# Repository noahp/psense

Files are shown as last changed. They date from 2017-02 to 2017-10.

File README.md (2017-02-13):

# psense
USB interfaced, 2-channel current + voltage meter.

# Schematic
[Schematic PDF here](psense.pdf)

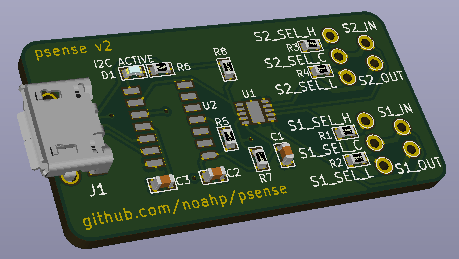
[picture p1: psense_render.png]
Render


# Parts
## USB
* USB to I2C interface
* bus powered, no external crystal needed

http://www.mouser.com/ProductDetail/Microchip-Technology/MCP2221A-I-SL

## Meter
* 2 channel current + bus voltage (0-40V)
* I2C interface
* adjustable range +/-10mV, 20mV, 40mV, 80mV

http://www.mouser.com/ProductDetail/Microchip/PAC1720-1-AIA-TR

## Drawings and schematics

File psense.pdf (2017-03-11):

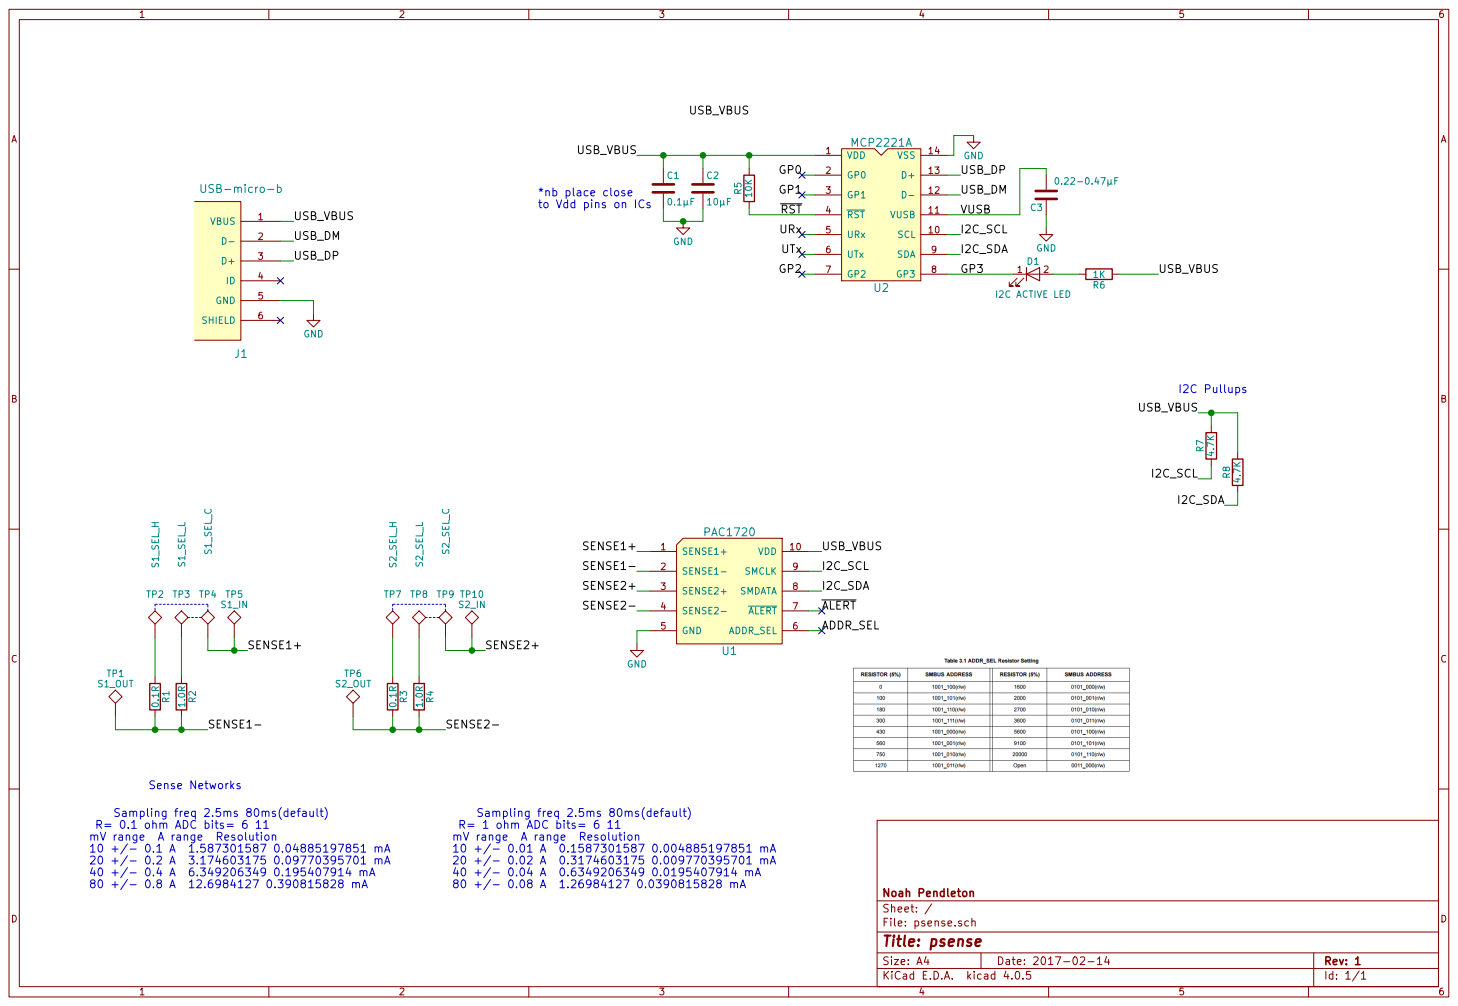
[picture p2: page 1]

*nb place close
to Vdd pins on ICs

Sampling freq 2.5ms 80ms(default)
R= 0.1 ohm ADC bits= 6 11
mV range A range Resolution

R= 1 ohm ADC bits= 6 11

File: psense.sch Sheet: / Noah Pendleton

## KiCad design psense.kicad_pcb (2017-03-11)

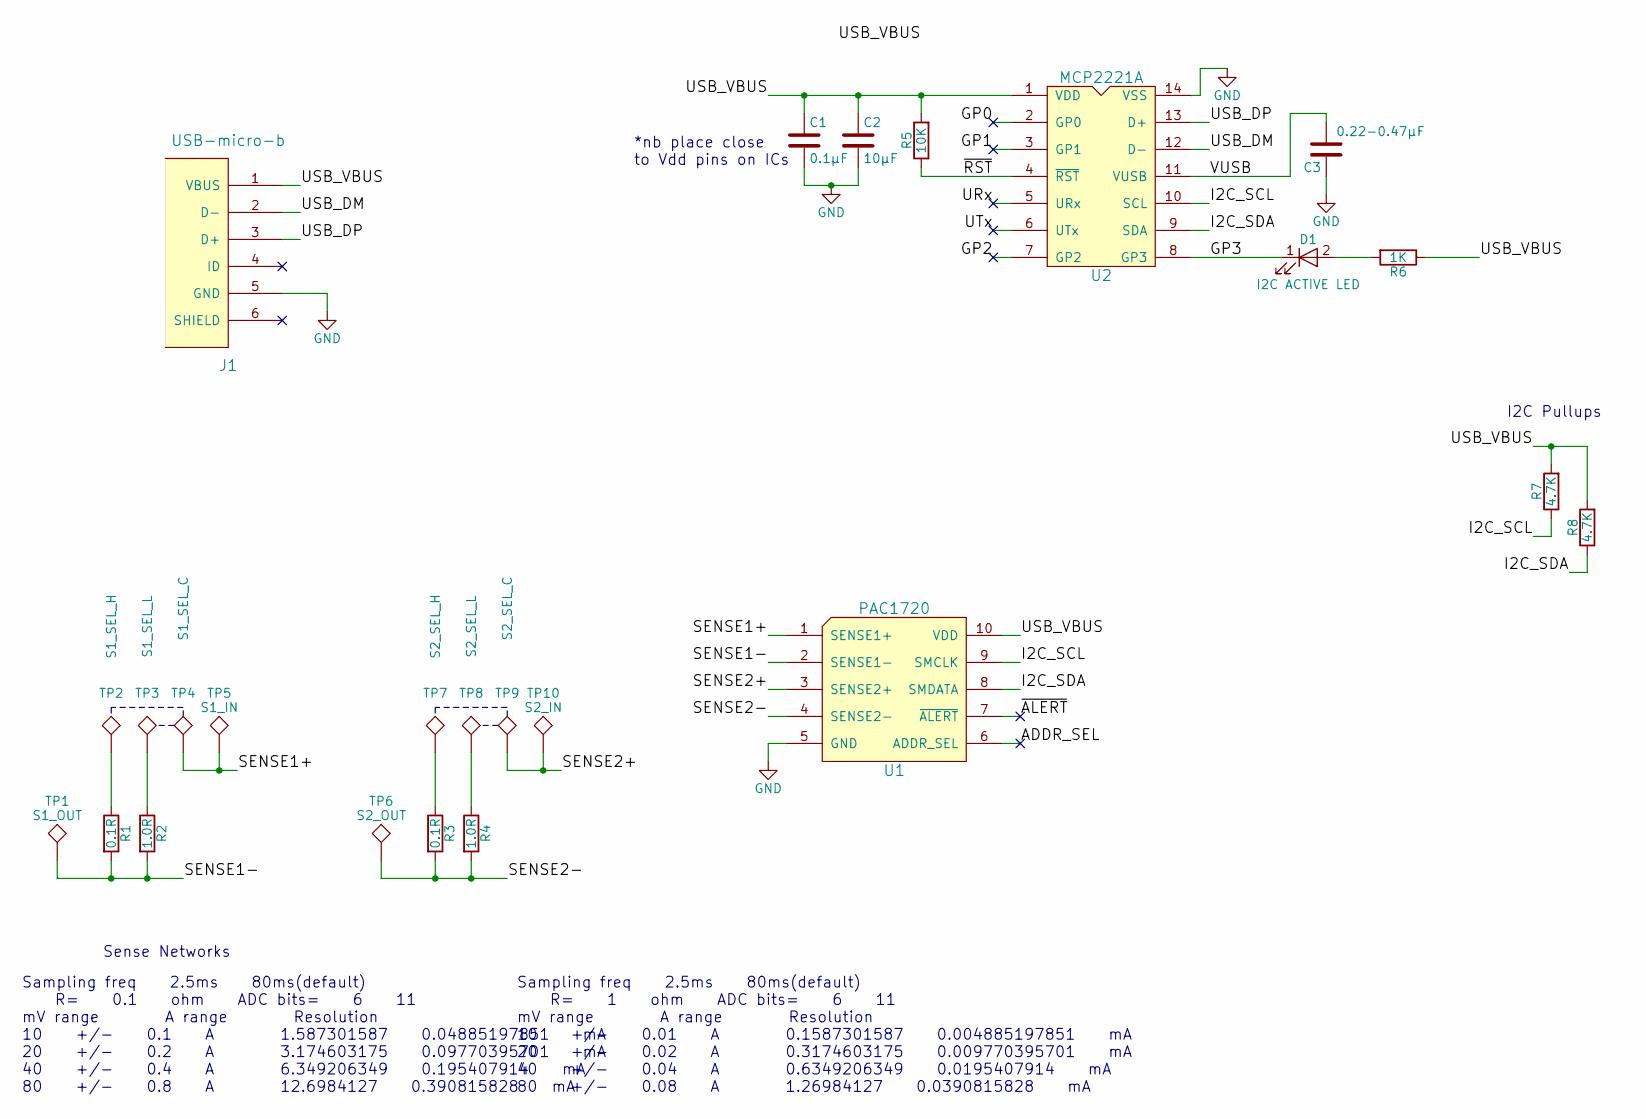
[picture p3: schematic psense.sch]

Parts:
C1: 0.1µF; SMD_0603_C
C2: 10µF; SMD_0603_C
C3: 0.22-0.47µF; SMD_0603_C
D1: I2C ACTIVE LED; SMD_0603_LED_REVERSED
J1: USB-micro-b; usb_micro_b_smt
R1, R3: 0.1R; SMD_0603_R
R2, R4: 1.0R; SMD_0603_R
R5: 10K; SMD_0603_R
R6: 1K; SMD_0603_R
R7, R8: 4.7K; SMD_0603_R
TP1: S1_OUT; TEST_0.100
TP2: S1_SEL_H; TEST_0.100
TP3: S1_SEL_L; TEST_0.100
TP4: S1_SEL_C; TEST_0.100
TP5: S1_IN; TEST_0.100
TP6: S2_OUT; TEST_0.100
TP7: S2_SEL_H; TEST_0.100
TP8: S2_SEL_L; TEST_0.100
TP9: S2_SEL_C; TEST_0.100
TP10: S2_IN; TEST_0.100
U1: PAC1720; SMD_10-DFN
U2: MCP2221A; SMD_14-SOIC

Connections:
/ADDR_SEL: U1.6 (ADDR_SEL)
/GP0: U2.2 (GP0)
/GP1: U2.3 (GP1)
/GP2: U2.7 (GP2)
/GP3: D1.1 (K), U2.8 (GP3)
/I2C_SCL: R7.1, U1.9 (SMCLK), U2.10 (SCL)
/I2C_SDA: R8.1, U1.8 (SMDATA), U2.9 (SDA)
/SENSE1+: TP4.1, TP5.1, U1.1 (SENSE1+)
/SENSE1-: R1.2, R2.2, TP1.1, U1.2 (SENSE1-)
/SENSE2+: TP9.1, TP10.1, U1.3 (SENSE2+)
/SENSE2-: R3.2, R4.2, TP6.1, U1.4 (SENSE2-)
/URx: U2.5 (URx)
/USB_DM: J1.2 (D-), U2.12 (D-)
/USB_DP: J1.3 (D+), U2.13 (D+)
/USB_VBUS: C1.1, C2.1, J1.1 (VBUS), R5.2, R6.1, R7.2, R8.2, U1.10 (VDD), U2.1 (VDD)
/UTx: U2.6 (UTx)
/VUSB: C3.2, U2.11 (VUSB)
/~ALERT: U1.7 (~ALERT)
/~RST: R5.1, U2.4 (~RST)
GND: C1.2, C2.2, C3.1, J1.5 (GND), U1.5 (GND), U2.14 (VSS)
unnamed: D1.2 (A), R6.2
unnamed: R1.1, TP2.1
unnamed: R2.1, TP3.1
unnamed: R3.1, TP7.1
unnamed: R4.1, TP8.1

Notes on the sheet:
I2C Pullups
Sense Networks
Sampling freq 2.5ms 80ms(default) R= 0.1 ohm ADC bits= 6 11 mV range A range Resolution 10 +/- 0.1 A 1.587301587 0.04885197851 mA 20 +/- 0.2 A 3.174603175 0.09770395701 mA 40 +/- 0.4 A 6.349206349 0.195407914 mA 80 +/- 0.8 A 12.6984127 0.390815828 mA
Sampling freq 2.5ms 80ms(default) R= 1 ohm ADC bits= 6 11 mV range A range Resolution 10 +/- 0.01 A 0.1587301587 0.004885197851 mA 20 +/- 0.02 A 0.3174603175 0.009770395701 mA 40 +/- 0.04 A 0.6349206349 0.0195407914 mA 80 +/- 0.08 A 1.26984127 0.0390815828 mA
*nb place close to Vdd pins on ICs

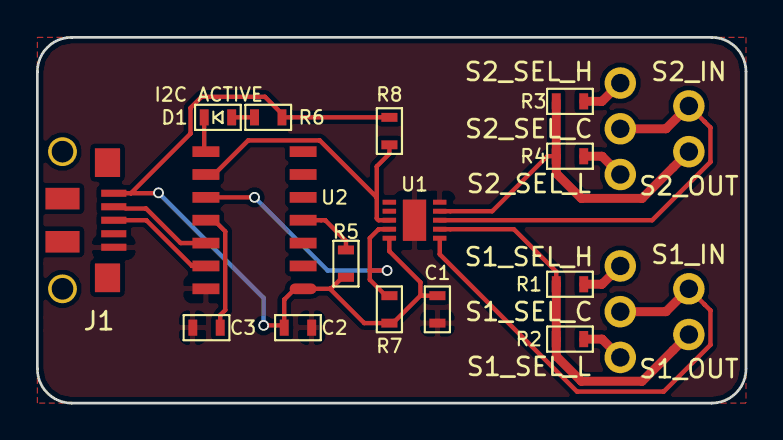
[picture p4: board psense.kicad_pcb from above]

Board: 2 copper layers, 39.4 x 20.3 mm, 25 parts (0 on the bottom side), 18 nets.

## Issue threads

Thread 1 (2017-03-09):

Fix/remove under footprint routing

noahp, 2017-03-09:
Clean up layout

Closed 2017-03-11.

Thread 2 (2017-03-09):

Swap Micro-usb connector for one with pegs

noahp, 2017-03-09:
http://www.mouser.com/ProductDetail/Amphenol-FCI/10118193-0001LF
https://s3.amazonaws.com/devpublic1/datasheets/10118193AC-197151.pdf

Closed 2017-03-11.

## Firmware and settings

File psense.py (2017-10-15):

#!/usr/bin/env python
'''
    MCP2221A + PAC1720 interface.

    Slightly better performance than the Microchip tools:
     ~ 50ms for a single byte register read using Microchip tools
     ~ 15ms using this tool (on windows 10 with pywinusb)
'''
import sys
import time
if sys.platform == 'win32':
    try:
        import pywinusb.hid as hid
    except ImportError:
        print 'Error, please `pip install pywinusb`'
        sys.exit(-1)
else:
    try:
        import usb.core
    except:
        print 'Error, please `pip install pyusb`'
        sys.exit(-1)


class Mcp2221aI2c(object):
    ''' I2C interface to MCP2221A '''

    CMD_MCP2221_STATUS = 0x10
    SUBCMD_STATUS_SPEED = 0x20
    CMD_MCP2221_RDDATA7 = 0x91
    CMD_MCP2221_GET_RDDATA = 0x40
    CMD_MCP2221_WRDATA7 = 0x90

    def __init__(self, bus_speed=100000, address=0x18):
        '''Optionally can be overridden by child class'''
        self.device = None
        self.reattach = []
        self.bus_speed = bus_speed
        self.address = address
        self.readdatatime = 0
        self.readdata = []

    def hidwrite(self, data):
        '''Write raw HID data to EP3. Stub that must be implemented in child class.'''
        raise NotImplementedError

    def hidread(self, timeout=100):
        '''Read raw HID data from EP3'''
        raise NotImplementedError

    def write(self, data, address=None):
        '''Execute I2C write, optional address override'''
        if not address:
            address = self.address

        outpacket = [
            Mcp2221aI2c.CMD_MCP2221_WRDATA7,
            len(data) & 0xFF,
            0,
            (address << 1) & 0xFF,
        ] + data
        # print 'write: ' + str(['%02X'%c for c in outpacket])
        self.hidwrite(outpacket)
        self.hidread()

        # status stage
        outpacket = [
            Mcp2221aI2c.CMD_MCP2221_STATUS
        ] + [0] * 7
        self.hidwrite(outpacket)
        self.hidread()

    def read(self, length, address=None):
        '''Execute I2C read, optional address override'''
        if not address:
            address = self.address

        outpacket = [
            Mcp2221aI2c.CMD_MCP2221_RDDATA7,
            length,  # length LSB
            0,  # length MSB, unsupported
            (address << 1) & 0xFF,  # don't set read bit
        ]
        self.hidwrite(outpacket)
        self.hidread()

        outpacket = [
            Mcp2221aI2c.CMD_MCP2221_GET_RDDATA,
        ]
        self.hidwrite(outpacket)
        readdata = self.hidread()
        if readdata[4] > 0:
            readdata = readdata[5:5 + readdata[4]]
        else:
            readdata = []
        return readdata

    def connect(self):
        '''Try to connect to the device. Stub that must be implemented in child class.'''
        raise NotImplementedError


class Mcp2221aI2cWin32(Mcp2221aI2c):
    '''Windows HID interface to MCP2221A'''

    def hidread(self, timeout=100):
        '''Raw HID read of input report id=0x00 on EP3, 64 bytes'''
        startime = time.time()
        endtime = startime + timeout / 1000.0
        data = []
        while (not len(data)) and (time.time() < endtime):
            if self.readdatatime > startime:
                data = self.readdata
            time.sleep(0.001)
        return data

    def __readhandler(self, data):
        self.readdata = data
        self.readdatatime = time.time()
        # print 'read: ' + str(data)

    def hidwrite(self, data):
        '''Raw HID write to output report id=0x00 on EP3, up to 64 bytes'''
        self.device.output_report.send([0x00] + data + [0] * (64 - len(data)))

    def connect(self):
        ''' Try to connect to the device '''
        devices = hid.HidDeviceFilter(
            vendor_id=0x04d8, product_id=0x00dd).get_devices()
        if len(devices):
            self.device = devices[0]
            self.device.open()

            # get the input/output reports
            self.device.input_report = self.device.find_input_reports()[0]
            self.device.output_report = self.device.find_output_reports()[0]

            # attach read handler
            self.device.set_raw_data_handler(self.__readhandler)

            outpacket = [
                Mcp2221aI2c.CMD_MCP2221_STATUS,
                0,
                0,
                Mcp2221aI2c.SUBCMD_STATUS_SPEED,
                12000000 / self.bus_speed - 3,
                0,
                0,
                0
            ]
            self.hidwrite(outpacket)
            self.hidread()

            return True
        else:
            return False


class Mcp2221aI2cUnix(Mcp2221aI2c):
    '''Linux HID interface to MCP2221A'''

    def hidread(self, timeout=100):
        '''Raw HID read of EP3, 64 bytes'''
        return self.device.read(0x83, 64, timeout)

    def hidwrite(self, data):
        '''Raw HID write to EP3, up to 64 bytes'''
        return self.device.write(0x03, data + [0] * (64 - len(data)))

    def connect(self):
        ''' Try to connect to the device '''
        dev = usb.core.find(idVendor=0x04d8, idProduct=0x00dd)

        if dev:
            print 'Found device'
            for i in range(3):
                if dev.is_kernel_driver_active(i):
                    self.reattach.append(i)
                    dev.detach_kernel_driver(i)
            dev.set_configuration()
            self.device = dev
            outpacket = [
                Mcp2221aI2c.CMD_MCP2221_STATUS,
                0,
                0,
                Mcp2221aI2c.SUBCMD_STATUS_SPEED,
                12000000 / self.bus_speed - 3,
                0,
                0,
                0
            ]
            self.hidwrite(outpacket)
            try:
                self.hidread()
            except usb.core.USBError:
                pass
            return True

        return False


if __name__ == '__main__':
    if sys.platform == 'win32':
        I2C = Mcp2221aI2cWin32()
    else:  # unix, probably
        I2C = Mcp2221aI2cUnix()

    if not I2C.connect():
        print 'Error connecting!'
        sys.exit(-1)

    print 'Reading PAC1720 Product ID register...'
    I2C.write([0xFD])  # write the register address
    data = I2C.read(1)  # read 1 byte
    print 'Product ID (expects 0x57): ' + ''.join('%c' % c for c in data).encode('hex')

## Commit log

2017-02-09 Add kicadlib submodule
2017-02-09 Add power sense IC and MCU
    [psense.kicad_pcb, psense.sch]
2017-02-12 Swap mcu for plain old usb-i2c converter
    [psense.sch]
2017-02-12 Update MCP2221 component
    [psense.sch]
2017-02-12 Most of schematic done
    [psense.sch]
2017-02-12 Finish schematic
    [psense.sch]
2017-02-12 No more sw! rearrange
    [psense.kicad_pcb, psense.sch]
2017-02-12 Link to schematic
2017-02-12 Layout done
    [psense-B.Cu.gbr, psense-B.Mask.gbr, psense-B.SilkS.gbr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]
2017-02-12 Add psense.kicad_pcb-bak to gitignore
2017-02-13 Tidy up a bit
    [psense-B.Cu.gbr, psense-B.Mask.gbr, psense-B.SilkS.gbr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]
2017-02-14 Add title page to schematic
    [psense.sch]
2017-02-18 Add partially working sample USB interface code
2017-02-19 Add some windows support, not working yet
    [psense.py]
2017-03-11 Fix https://github.com/noahp/psense/issues/1 https://github.com/noahp/psense/issues/2 https://github.com/noahp/psense/issues/3
    [psense-B.Cu.gbr, psense-B.Mask.gbr, psense-B.SilkS.gbr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]
2017-03-11 Update render
    [psense.sch]
